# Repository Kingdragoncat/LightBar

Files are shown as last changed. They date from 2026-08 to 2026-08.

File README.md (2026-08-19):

# LightBar

simple extendable light bar meant to be mounted to whatever project you want. just chain em together and go

## what is this thing

its a PCB with 21 WS2812B addressable LEDs on it. theres connectors on both ends so you can daisy chain multiple bars together. each LED has its own 100nF bypass cap. theres also mounting holes on each end so you can screw it down to stuff

front render

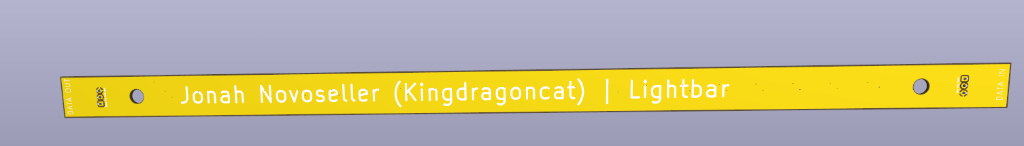
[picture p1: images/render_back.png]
back render


## pcb layout

pcb front

pcb back

## schematic

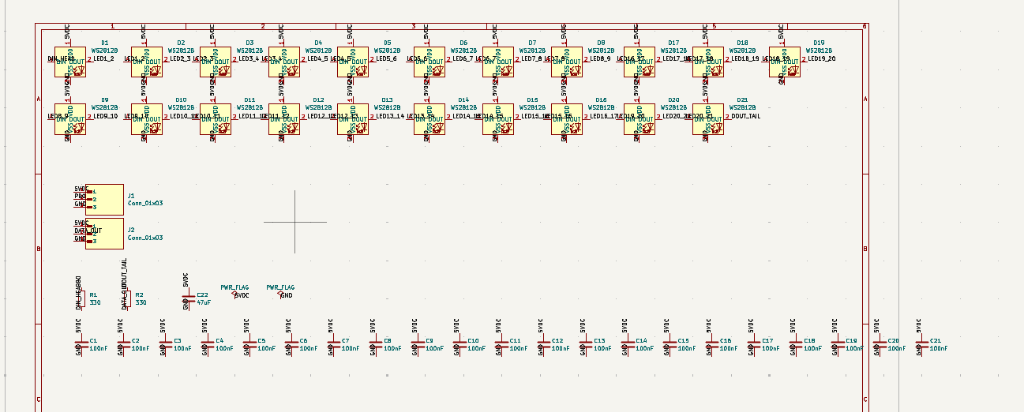
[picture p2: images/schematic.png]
schematic


## specs

- 21x WS2812B addressable RGB LEDs
- 5V power
- data in/out connectors on both ends for daisy chaining
- 100nF decoupling cap per LED
- 47uF bulk cap on the power rail
- 330 ohm resistors on data lines
- mounting holes on both ends
- designed in KiCad

## wiring

hook up 5V, GND, and data to the input connector and youre good. if you want more bars just connect the output of one to the input of the next

## BOM

| Ref | Qty | Value | Package | Description | Unit Price | Subtotal | Link |
|-----|-----|---|---|---|---|---|---|
| D1-D21 | 21 | WS2812B | 5050 PLCC4 | Addressable RGB LED | $0.11 | $2.31 | [LCSC](https://www.lcsc.com/product-detail/Light-Emitting-Diodes-LED_Worldsemi-WS2812B-B-W_C2761795.html) |
| C1-C21 | 21 | 100nF | 1206 | Ceramic decoupling cap | $0.03 | $0.63 | [LCSC](https://www.lcsc.com/product-detail/Walsin-1206B104K500CT_C93194.html) |
| C22 | 1 | 47uF | 1210 | Ceramic bulk cap | $0.25 | $0.25 | [LCSC](https://www.lcsc.com/product-detail/TORCH-CT4G-1210-X5R-16V-47uF-K_C2960960.html) |
| R1, R2 | 2 | 330Ω | 1206 | SMD resistor | $0.01 | $0.02 | [LCSC](https://www.lcsc.com/search?q=1206%20330%20ohm) |
| J1, J2 | 2 | Conn_01x03 | JST XH 3-pin | Through-hole connector (S3B-XH-A) | $0.08 | $0.16 | [LCSC](https://www.lcsc.com/product-detail/JST-S3B-XH-A-LF-SN_C157928.html) |

**total: 47 parts — ~$3.37**

## license

do whatever you want with it honestly

---

made by Jonah Novoseller (Kingdragoncat)

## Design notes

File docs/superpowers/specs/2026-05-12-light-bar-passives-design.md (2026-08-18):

# Light Bar — Passives (decoupling caps + data series resistors)

**Date:** 2026-05-12
**Project:** `Light Bar` (KiCad 9) — 21× WS2812B RGB LED bar
**Scope of this spec:** add the passive support components to the schematic. PCB placement and net wiring are the *next* task and are out of scope here (only the intended net plan is recorded for reference).

## Context / current state

- `Light Bar.kicad_sch` contains: D1–D21 = `LED:WS2812B` (`LED_SMD:LED_WS2812B_PLCC4_5.0x5.0mm_P3.2mm`), J1 + J2 = `Conn_01x03` (`Connector_JST:JST_XH_S3B-XH-A_1x03_P2.50mm_Horizontal`), and one `power:GND` symbol. **The schematic is not yet wired (0 wires).**
- Connector pinout (both J1 and J2, 3-pin): **GND · PB0 (data) · 5VDC**. J1 = power + data in; J2 = passthrough out. Data net name = `PB0` (matches the host MCU pin).
- Visual goal: passives should look clean/uniform on the bar → **1206 SMD for all resistors and the per-LED caps**; bulk cap kept low-profile SMD.

## Components to add

| Ref | Value | Footprint | Symbol | Qty | Role |
|---|---|---|---|---|---|
| C1–C21 | 100 nF, 50 V, X7R | `Capacitor_SMD:C_1206_3216Metric` | `Device:C` | 21 | VDD↔GND decoupling, one per WS2812B; numbered to match LEDs (C1↔D1 … C21↔D21) |
| C22 | 47 µF, 16 V, X5R MLCC | `Capacitor_SMD:C_1210_3225Metric` | `Device:C` | 1 | bulk reservoir on the 5VDC rail, placed by J1 |
| R1 | 330 Ω, 1/4 W | `Resistor_SMD:R_1206_3216Metric` | `Device:R` | 1 | series resistor on data IN: `J1.PB0 → R1 → D1.DIN` |
| R2 | 330 Ω, 1/4 W | `Resistor_SMD:R_1206_3216Metric` | `Device:R` | 1 | series resistor on data OUT: `D21.DOUT → R2 → J2.PB0` |

All symbols and footprints ship with KiCad 9 and are already registered in the user's global library tables — nothing to install.

### Value rationale
- **100 nF / LED:** the WorldSemi WS2812B datasheet recommends a 100 nF decoupling cap between VDD and VSS at every LED.
- **47 µF bulk:** 21 LEDs ≈ 1.3 A peak at full white; a ~47 µF reservoir near the input smooths inrush/ripple. A 1210 X5R MLCC keeps it low-profile and non-polarized (so `Device:C`, not `Device:C_Polarized`). Alternative considered: 3× 10 µF 1206 in parallel for visual uniformity — rejected in favour of a single part unless the user prefers it.
- **330 Ω series:** standard WS2812B data-line damping value (Adafruit/WorldSemi reference designs). 470 Ω was offered as an alternative; 330 Ω chosen.

## Intended net plan (for the wiring task that follows — not implemented here)

- `5VDC` (a.k.a. `+5V`): `J1.5VDC` — `C22` — every `D1..D21 VDD` (each with its own `C1..C21` to GND) — `J2.5VDC`
- `GND`: common to `J1`, `J2`, `C22`, all LED `VSS`, all caps
- `PB0` (data): `J1.PB0` → `R1` → `D1.DIN`; `D1.DOUT → D2.DIN → … → D21.DOUT` → `R2` → `J2.PB0`
- Exact pin-number ↔ signal mapping on the JST (which of pins 1/2/3 is GND/PB0/5VDC) to be confirmed during wiring.

## Out of scope
- Schematic wiring / net labels / power flags.
- PCB component placement and routing (copper pours, trace widths for the 5 V rail, etc.).
- BOM/CPL export, manufacturing outputs.

## Notes
- The project directory is not a git repository, so this spec is saved but not committed.

## Implementation log (2026-05-12)
- Added to `Light Bar.kicad_sch`: C1–C21 (100 nF, `Capacitor_SMD:C_1206_3216Metric`), C22 (47 µF, `C_1210_3225Metric`), R1/R2 (330 Ω, `R_1206_3216Metric`), plus `#FLG01`/`#FLG02` PWR_FLAGs on the 5VDC and GND nets. Existing D1–D21, J1, J2 left in place.
- Wired with net labels: `5VDC` (45 nodes: 22 cap pin-1 + 21 LED VDD + J1.1 + J2.1), `GND` (45 nodes: 22 cap pin-2 + 21 LED VSS + J1.3 + J2.3 + #PWR01), `PB0` (J1.2–R1.1), `DIN_HEAD` (R1.2–D1.DIN), chain `LED1_2 … LED20_21` (D_n.DOUT–D_{n+1}.DIN), `DOUT_TAIL` (D21.DOUT–R2.1), `DATA_OUT` (R2.2–J2.2).
- ERC: 0 errors. 2 remaining warnings (`lib_symbol_issues`): J1/J2 still carry lib_id `S3B-XH-A_LF__SN_:…`; the symbol is embedded in the schematic so it works, but the source library was removed earlier. Cosmetic only — fixable by swapping J1/J2 to a stock connector symbol in Eeschema.
- Backup of pre-wiring schematic: `Light Bar.kicad_sch.bak-before-wiring`. Stale `.lck` / autosave for the schematic removed (autosave was byte-identical to the pre-wiring file).
## PCB layout (2026-05-12)
- Board: **350 mm × 16 mm** rectangle on Edge.Cuts. (Lengthened/widened from the original ~300×12 so the 1206-cap gaps + 5V + data routing fit.)
- Placement: D1–D21 rot 180 in a single row at 13 mm pitch (x = 51…311, y = 8); decoupling caps C1–C20 horizontal in the gaps (y=8.5), C21 above D21; C22 (bulk) + R1 by J1 at the left end; R2 by J2 at the right end; J1 (rot 90) at the left end and J2 (rot 270) at the right end — both oriented so the cable exits straight off the end with the housing back toward the LEDs; H1 (x=30) and H2 (x=326) = `MountingHole:MountingHole_5.3mm_M5`, on the centerline near each end.
- Copper: **GND pour on B.Cu** over the whole board (inset 1 mm) + 43 stitching vias on every SMD GND pad (LEDs + caps); J1/J2 GND pads are THT so they tie to the pour directly. **5V on F.Cu** — a 0.6 mm rail along the bottom edge (y=11.5) from x=9 to x=335, popping up to every LED VDD pad and every cap 5VDC pad, with a single via near J2 hopping the 5V onto B.Cu to reach J2 pad-1 (avoids crossing the data-out trace). **Data chain on F.Cu** (0.25 mm) — D_n DOUT → D_(n+1) DIN weaving through each gap above the decoupling cap; J1.PB0→R1→D1.DIN and D21.DOUT→R2→J2.pad-2 routed at the ends (around the M5 holes).
- DRC: **0 errors**, schematic-parity OK. Warnings only: 43 "via dangling" + 44 "unconnected" — both are GND-pour artifacts of `kicad-cli` not filling zones; they clear as soon as the board is opened in pcbnew (zone auto-fills, or press `B`). Plus 23 "footprint differs from library" (from normalizing silk text rotation) and a couple silk-near-edge warnings — all cosmetic. `courtyards_overlap` (M5 hole H2 near J2 — intentional close placement, no physical conflict) was set to "warning" in `.kicad_pro`.
- Backups in the project folder: `Light Bar.kicad_pcb.bak-before-layout`, `.STAGE1-placed`, `.STAGE2-geo`, `.STAGE3-connectors`, `.STAGE4-before-route`, `.STAGE5-routed-2026-05-12`.
- Remaining: open pcbnew → refill zones (`B`) → review; then manufacturing outputs (gerbers / drill / BOM / CPL) for fab.

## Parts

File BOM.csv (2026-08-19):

Reference | Qty | Value | Package | Description | Unit Price | Subtotal | Link
D1-D21 | 21 | WS2812B | 5050 PLCC4 | Addressable RGB LED | $0.11 | $2.31 | https://www.lcsc.com/product-detail/Light-Emitting-Diodes-LED_Worldsemi-WS2812B-B-W_C2761795.html
C1-C21 | 21 | 100nF | 1206 | Ceramic decoupling capacitor | $0.03 | $0.63 | https://www.lcsc.com/product-detail/Walsin-1206B104K500CT_C93194.html
C22 | 1 | 47uF | 1210 | Ceramic bulk capacitor | $0.25 | $0.25 | https://www.lcsc.com/product-detail/TORCH-CT4G-1210-X5R-16V-47uF-K_C2960960.html
R1, R2 | 2 | 330 | 1206 | SMD resistor | $0.01 | $0.02 | https://www.lcsc.com/search?q=1206%20330%20ohm
J1, J2 | 2 | Conn_01x03 | JST XH 3-pin | Through-hole right angle connector (S3B-XH-A) | $0.08 | $0.16 | https://www.lcsc.com/product-detail/JST-S3B-XH-A-LF-SN_C157928.html
 |  |  |  |  | TOTAL |  | $3.37

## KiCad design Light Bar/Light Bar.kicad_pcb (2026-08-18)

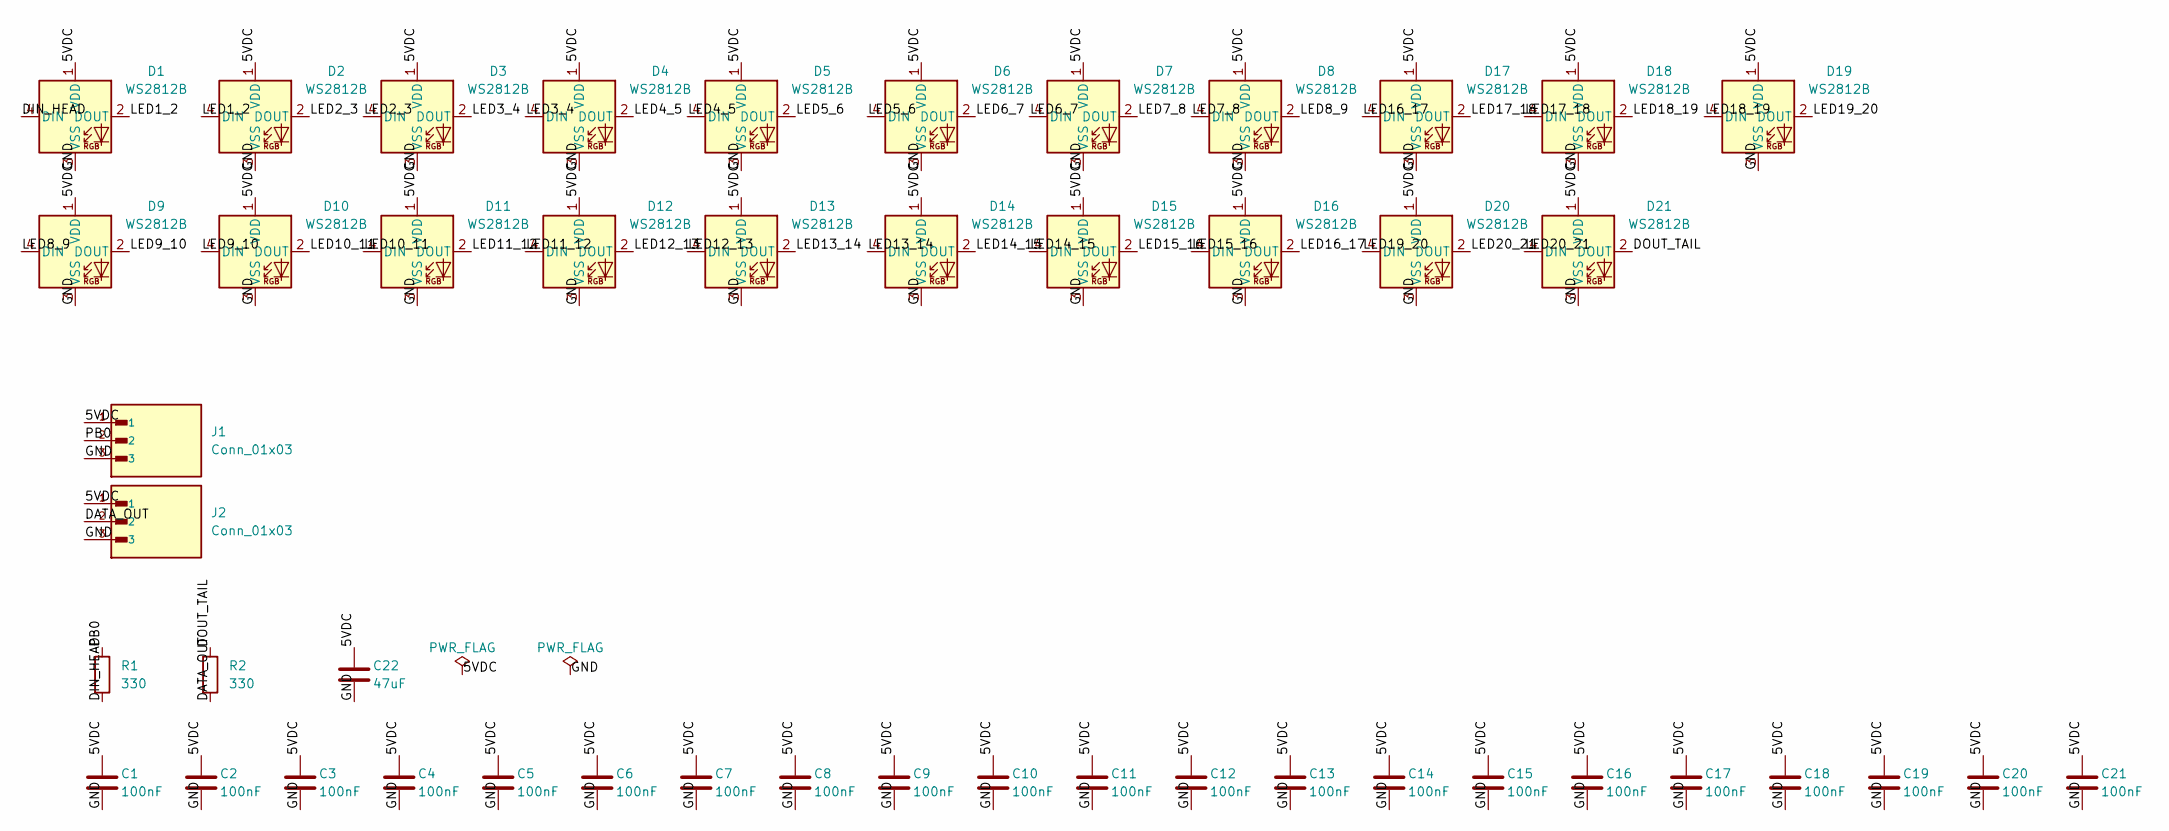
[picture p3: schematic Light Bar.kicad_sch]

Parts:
C1, C2, C3, C4, C5, C6, C7, C8, C9, C10, C11, C12, C13, C14, C15, C16, C17, C18, C19, C20, C21: 100nF; C_1206_3216Metric
C22: 47uF; C_1210_3225Metric
D1, D2, D3, D4, D5, D6, D7, D8, D9, D10, D11, D12, D13, D14, D15, D16, D17, D18, D19, D20, D21: WS2812B; LED_WS2812B_PLCC4_5.0x5.0mm_P3.2mm
J1, J2: Conn_01x03; JST_XH_S3B-XH-A_1x03_P2.50mm_Horizontal
R1, R2: 330; R_1206_3216Metric

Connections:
/5VDC: C1.1, C2.1, C3.1, C4.1, C5.1, C6.1, C7.1, C8.1, C9.1, C10.1, C11.1, C12.1, C13.1, C14.1, C15.1, C16.1, C17.1, C18.1, C19.1, C20.1, C21.1, C22.1, D1.1 (VDD), D2.1 (VDD), D3.1 (VDD), D4.1 (VDD), D5.1 (VDD), D6.1 (VDD), D7.1 (VDD), D8.1 (VDD), D9.1 (VDD), D10.1 (VDD), D11.1 (VDD), D12.1 (VDD), D13.1 (VDD), D14.1 (VDD), D15.1 (VDD), D16.1 (VDD), D17.1 (VDD), D18.1 (VDD), D19.1 (VDD), D20.1 (VDD), D21.1 (VDD), J1.1, J2.1
/DATA_OUT: J2.2, R2.2
/DIN_HEAD: D1.4 (DIN), R1.2
/DOUT_TAIL: D21.2 (DOUT), R2.1
/LED1_2: D1.2 (DOUT), D2.4 (DIN)
/LED2_3: D2.2 (DOUT), D3.4 (DIN)
/LED3_4: D3.2 (DOUT), D4.4 (DIN)
/LED4_5: D4.2 (DOUT), D5.4 (DIN)
/LED5_6: D5.2 (DOUT), D6.4 (DIN)
/LED6_7: D6.2 (DOUT), D7.4 (DIN)
/LED7_8: D7.2 (DOUT), D8.4 (DIN)
/LED8_9: D8.2 (DOUT), D9.4 (DIN)
/LED9_10: D9.2 (DOUT), D10.4 (DIN)
/LED10_11: D10.2 (DOUT), D11.4 (DIN)
/LED11_12: D11.2 (DOUT), D12.4 (DIN)
/LED12_13: D12.2 (DOUT), D13.4 (DIN)
/LED13_14: D13.2 (DOUT), D14.4 (DIN)
/LED14_15: D14.2 (DOUT), D15.4 (DIN)
/LED15_16: D15.2 (DOUT), D16.4 (DIN)
/LED16_17: D16.2 (DOUT), D17.4 (DIN)
/LED17_18: D17.2 (DOUT), D18.4 (DIN)
/LED18_19: D18.2 (DOUT), D19.4 (DIN)
/LED19_20: D19.2 (DOUT), D20.4 (DIN)
/LED20_21: D20.2 (DOUT), D21.4 (DIN)
/PB0: J1.2, R1.1
GND: C1.2, C2.2, C3.2, C4.2, C5.2, C6.2, C7.2, C8.2, C9.2, C10.2, C11.2, C12.2, C13.2, C14.2, C15.2, C16.2, C17.2, C18.2, C19.2, C20.2, C21.2, C22.2, D1.3 (VSS), D2.3 (VSS), D3.3 (VSS), D4.3 (VSS), D5.3 (VSS), D6.3 (VSS), D7.3 (VSS), D8.3 (VSS), D9.3 (VSS), D10.3 (VSS), D11.3 (VSS), D12.3 (VSS), D13.3 (VSS), D14.3 (VSS), D15.3 (VSS), D16.3 (VSS), D17.3 (VSS), D18.3 (VSS), D19.3 (VSS), D20.3 (VSS), D21.3 (VSS), J1.3, J2.3

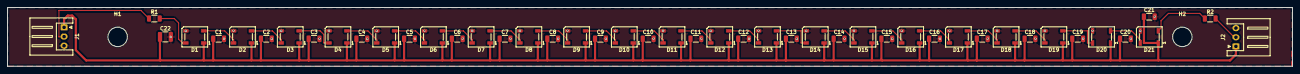
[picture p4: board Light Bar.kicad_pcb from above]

Board: 2 copper layers, 350.0 x 16.0 mm, 49 parts (0 on the bottom side), 26 nets.

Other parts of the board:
H1, H2: MountingHole_5.3mm_M5

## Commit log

2026-08-18 add BOM csv and update readme with BOM table and links
    [BOM.csv]
2026-08-19 add prices to BOM
    [BOM.csv, Light Bar.kicad_pcb]
